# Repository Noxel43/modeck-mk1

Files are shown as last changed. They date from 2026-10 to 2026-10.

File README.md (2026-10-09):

# modeck. mk1

*A fully open-source, DIY MP3 Player*

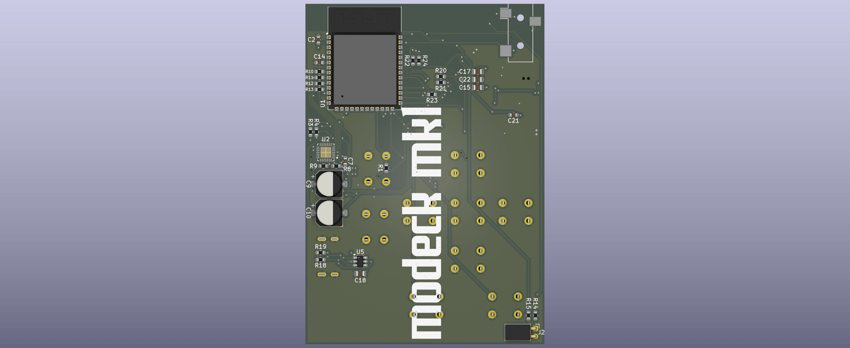
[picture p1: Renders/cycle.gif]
PCB Render


## Core Features:
- Loads of buttons (9) that are each mappable
- ~~Lovely tactile feel~~ (I lie, currently, for prototyping, I'm just using 6mm tacts, however, I really want to incorporate keyboard switches)
- Physical EQ. A potentiometer (currently twist, but I will make it slide) that controls the EQ
- Colour LCD screen (170x320 res)
- USB-C charging (I plan to incorporate pogo pins on the back)
- SD card for storage - easily transfer songs
- Stereo audio (why am I mentioning this, who wants a mono mp3 player?)
- 2 Layer PCB. The PCB consists of only two layers, so its cheap to produce.
- Possible WiFi/BT. For the PCB, I am using the [ESP32-S3-WROOM-1](https://www.altronics.com.au/product/z6433-esp-32s3-development-board), which has WiFi and a built in atenna. It's not currently a priority, but streaming, or at least downloading from wifi would be cool.

## Core Components:
***Note:** This is the list of* main *components, not a full BOM, which will be added later.*
- [ESP32-S3-WROOM-1](https://www.altronics.com.au/product/z6433-esp-32s3-development-board)
  - This is the main MCU, i.e. the brains
- [ES8388](http://lcsc.com/product-detail/C365736.html)
  - This is the audio codec, handling all of the audio output
- [Waveshare 1.9" LCD screen, SKU: 23822](https://www.waveshare.com/1.9inch-lcd-module.htm)
  - Used as the screen (duh). Can be substituted for any 1.9" screen.
- [Battery](https://www.youtube.com/watch?v=dQw4w9WgXcQ&list=RDdQw4w9WgXcQ&start_radio=1)
  - I'm writing this on my school laptop and I can't remember what I'm using specifically, but it's a LiPo. Watch this spot.

## Specifications:

placeholder

## Timeline:

#### **Current Phase:** Prototyping & EVT

*making sure everything works, not yet usable by public*
***Timeframe:** next month or two*

**Current:** PCB design done

**Next:**
- [ ] Make basic firmware for audio playback only
- [ ] Add input handling for all buttons
- [ ] Add a GUI for the screens
- [ ] Add EQ

#### **Next Phase:** DVT & Release

*design validation test, i.e. adding the case, etc*
***Timeframe (from phase start):** ~1 month*

- [ ] Create enclosure
- [ ] Ensure easy printability and assembly
- [ ] Publish v1 with guides, etc, ready without a polished firmware, if people want to make their own.
- [ ] Polish firmware, add different modes, and a good UI/UX
- [ ] Release full.

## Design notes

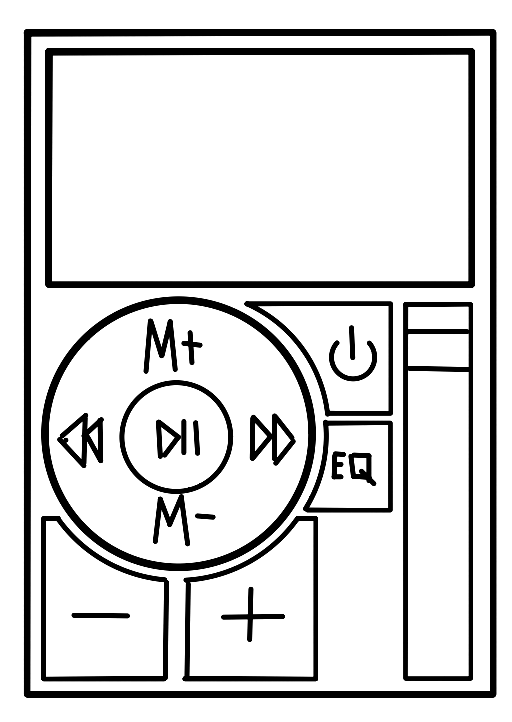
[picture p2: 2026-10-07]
ref.png

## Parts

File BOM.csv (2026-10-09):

Ref | Qty | Value | Unit | Price (ea) | Price (tot) | Footprint/Type | MFN | Link
C1 | 1 | 22 | µF | $- | $- | Capacitor_SMD:C_0805_2012Metric | CL21A226MAQNNNE | https://www.digikey.com/en/products/result?keywords=CL21A226MAQNNNE
C2,C4,C5,C14,C16,C21 | 6 | 100 | nF | $- | $- | Capacitor_SMD:C_0603_1608Metric | GRM188R71H104KA93D | https://www.digikey.com/en/products/result?keywords=GRM188R71H104KA93D
C3,C6,C7,C11,C12,C13 | 6 | 1 | µF | $- | $- | Capacitor_SMD:C_0603_1608Metric | CL10A105KB8NNNC | https://www.digikey.com/en/products/result?keywords=CL10A105KB8NNNC
C8,C15,C17,C18,C22 | 5 | 10 | µF | $- | $- | Capacitor_SMD:C_0805_2012Metric | CL21A106KAYNNNE | https://www.digikey.com/en/products/result?keywords=CL21A106KAYNNNE
C9,C10 | 2 | 220 | µF | $- | $- | Capacitor_SMD:CP_Elec_6.3x5.4 | EEE-FK0J221P | https://www.digikey.com/en/products/result?keywords=EEE-FK0J221P
C19,C20 | 2 | 4.7 | µF | $- | $- | Capacitor_SMD:C_0805_2012Metric | CL21A475KAQNNNE | https://www.digikey.com/en/products/result?keywords=CL21A475KAQNNNE
D1 | 1 | LED | N/A | $0.19 | $0.19 | LED_SMD:LED_0603_1608Metric | 150060VS55040 | https://www.digikey.com/en/products/detail/w%C3%BCrth-elektronik/150060VS55040/8557182
J1 | 1 | AudioJack3 | N/A | $0.68 | $0.68 | Connector_Audio:Jack_3.5mm_CUI_SJ-3523-SMT_Horizontal | STX-3000 | https://www.digikey.com/en/products/result?keywords=STX-3000
J2 | 1 | Battery | N/A | $- | $- | Connector_PinSocket_2.00mm:PinSocket_1x02_P2.00mm_Horizontal | N/A
J3 | 1 | USB_C | N/A | $2.35 | $2.35 | Connector_USB:USB_C_Receptacle_Amphenol_124019772112A | 124019772112A | https://www.digikey.com/en/products/detail/amphenol-cs-commercial-products/124019772112A/13683231
J4 | 1 | Micro_SD_Card | N/A | $3.41 | $3.41 | Connector_Card:microSD_HC_Wuerth_693072010801 | 6.93072E+11 | https://www.digikey.com/en/products/detail/w%C3%BCrth-elektronik/693072010801/3124584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
J5 | 1 | TFT SPI | N/A | $- | $- | Connector_JST:JST_GH_SM08B-GHS-TB_1x08-1MP_P1.25mm_Horizontal | N/A
R1,R2,R5,R6,R8,R9,R20,R21,R22,R23,R24 | 11 | 10 | kΩ | $- | $- | Resistor_SMD:R_0603_1608Metric | RC0603FR-0710KL | https://www.digikey.com/en/products/result?keywords=RC0603FR-0710KL
R3 | 1 | 5.1 | Ω | $- | $- | Resistor_SMD:R_0603_1608Metric | RC0603FR-075R1L | https://www.digikey.com/en/products/result?keywords=RC0603FR-075R1L
R4 | 1 | 4.7 | Ω | $- | $- | Resistor_SMD:R_0603_1608Metric | RC0603FR-074R7L | https://www.digikey.com/en/products/result?keywords=RC0603FR-074R7L
R7 | 1 | 0 | Ω | $- | $- | Resistor_SMD:R_0603_1608Metric | RC0603JR-070RL | https://www.digikey.com/en/products/result?keywords=RC0603JR-070RL
R10,R11,R12,R13 | 4 | 33 | Ω | $- | $- | Resistor_SMD:R_0603_1608Metric | RC0603FR-0733RL | https://www.digikey.com/en/products/result?keywords=RC0603FR-0733RL
R14,R15 | 2 | 100 | kΩ | $- | $- | Resistor_SMD:R_0603_1608Metric | RC0603FR-07100KL | https://www.digikey.com/en/products/result?keywords=RC0603FR-07100KL
R16 | 1 | 1 | kΩ | $- | $- | Resistor_SMD:R_0603_1608Metric | RC0603FR-071KL | https://www.digikey.com/en/products/result?keywords=RC0603FR-071KL
R17 | 1 | 2 | kΩ | $- | $- | Resistor_SMD:R_0603_1608Metric | RC0603FR-072KL | https://www.digikey.com/en/products/result?keywords=RC0603FR-072KL
R18,R19 | 2 | 5.1 | kΩ | $- | $- | Resistor_SMD:R_0603_1608Metric | RC0603FR-075K1L | https://www.digikey.com/en/products/result?keywords=RC0603FR-075K1L
RV1 | 1 | Slide pot | N/A | $0.28 | $0.28 | Potentiometer_SMD:Potentiometer_ACP_CA6-VSMD_Vertical | TC33X-2-203E | https://www.digikey.com/en/products/detail/bourns-inc/TC33X-2-203E/2566887
SW1 | 1 | Play | N/A | $0.10 | $0.10 | Button_Switch_THT:SW_PUSH_6mm_H4.3mm | 1825910-6 | https://www.digikey.com/en/products/result?keywords=1825910-6
SW2 | 1 | Trk Prev | N/A | $0.10 | $0.10 | Button_Switch_THT:SW_PUSH_6mm_H4.3mm | 1825910-6 | https://www.digikey.com/en/products/result?keywords=1825910-6
SW3 | 1 | Trk Next | N/A | $0.10 | $0.10 | Button_Switch_THT:SW_PUSH_6mm_H4.3mm | 1825910-6 | https://www.digikey.com/en/products/result?keywords=1825910-6
SW4 | 1 | Mode Prev | N/A | $0.10 | $0.10 | Button_Switch_THT:SW_PUSH_6mm_H4.3mm | 1825910-6 | https://www.digikey.com/en/products/result?keywords=1825910-6
SW5 | 1 | Mode Next | N/A | $0.10 | $0.10 | Button_Switch_THT:SW_PUSH_6mm_H4.3mm | 1825910-6 | https://www.digikey.com/en/products/result?keywords=1825910-6
SW6 | 1 | Eq | N/A | $0.10 | $0.10 | Button_Switch_THT:SW_PUSH_6mm_H4.3mm | 1825910-6 | https://www.digikey.com/en/products/result?keywords=1825910-6
SW7 | 1 | Power | N/A | $0.10 | $0.10 | Button_Switch_THT:SW_PUSH_6mm_H4.3mm | 1825910-6 | https://www.digikey.com/en/products/result?keywords=1825910-6
SW8 | 1 | RESET | N/A | $0.58 | $0.58 | Button_Switch_SMD:SW_SPST_PTS810 | PTS810SJM250SMTR LFS | https://www.digikey.com/en/products/detail/c-k/PTS810SJM250SMTR-LFS/4176610
SW9 | 1 | BOOT | N/A | $0.58 | $0.58 | Button_Switch_SMD:SW_SPST_PTS810 | PTS810SJM250SMTR LFS | https://www.digikey.com/en/products/detail/c-k/PTS810SJM250SMTR-LFS/4176610
SW10 | 1 | Power_sw | N/A | $2.51 | $2.51 | Button_Switch_SMD:SW_DIP_SPSTx01_Slide_6.7x4.1mm_W6.73mm_P2.54mm_LowProfile_JPin | SDA01H1SBD | https://www.digikey.com/en/products/detail/c-k/SDA01H1SBD/2263273
SW11 | 1 | Next | N/A | $0.10 | $0.10 | Button_Switch_THT:SW_PUSH_6mm_H4.3mm | 1825910-6 | https://www.digikey.com/en/products/result?keywords=1825910-6
SW12 | 1 | Prev | N/A | $0.10 | $0.10 | Button_Switch_THT:SW_PUSH_6mm_H4.3mm | 1825910-6 | https://www.digikey.com/en/products/result?keywords=1825910-6
U1 | 1 | ESP32-S3-WROOM-1 | N/A | $6.10 | $6.10 | RF_Module:ESP32-S3-WROOM-1 | ESP32-S3-WROOM-1-N16 | https://www.digikey.com/en/products/detail/espressif-systems/esp32-s3-wroom-1-n16/16162647
U2 | 1 | ES8388 | N/A | $1.12 | $1.12 | Package_DFN_QFN:QFN-28-1EP_4x4mm_P0.45mm_EP2.6x2.6mm | ES8388 | https://www.lcsc.com/product-detail/C365736.html
U3 | 1 | AP2112K-3.3 | N/A | $0.28 | $0.28 | Package_TO_SOT_SMD:SOT-23-5 | AP2112K-3.3TRG1 | https://www.digikey.com/en/products/detail/diodes-incorporated/ap2112k-3-3trg1/4470746
U4 | 1 | MCP73831-2-OT | N/A | $0.76 | $0.76 | Package_TO_SOT_SMD:SOT-23-5 | MCP73831T-2ACI/OT | https://www.digikey.com/en/products/detail/microchip-technology/MCP73831T-2ACI-OT/964301
U5 | 1 | USBLC6-2SC6 | N/A | $0.86 | $0.86 | Package_TO_SOT_SMD:SOT-23-6 | USBLC6-2SC6 | https://www.digikey.com/en/products/detail/goodwork/usblc6-2sc6/29515591
Screen | 1 | 1.9 | " | $11.99 | $11.99 | N/A | 23822 | https://www.waveshare.com/1.9inch-lcd-module.htm
Battery | 1 | 2000 | mA | $14.45 | $10.00 | N/A | CE04378 | https://core-electronics.com.au/polymer-lithium-ion-battery-2000mah-38459.html
Capacitors + Resistors | 1 | Just approx | N/A | 10 | $10.00
Total |  |  |  |  | $52.59

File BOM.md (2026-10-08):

# modeck mk1 – bill of materials

<!-- Generated by Half Life from project cmuur4mu709pu01smvrzood28. Edits here are overwritten on the next sync. -->
<!-- Generated: 1970-01-01T00:00:00.000Z -->

> [!NOTE]
> This parts list is mirrored from [Half Life](https://halflife.hackclub.com). Editing it here will not change the platform's copy, and the next sync overwrites this file.

| Week | Tier | Parts funding |
| --- | --- | --- |
| Week 1 | Tier 2 | $65.00 |

_No parts listed yet._

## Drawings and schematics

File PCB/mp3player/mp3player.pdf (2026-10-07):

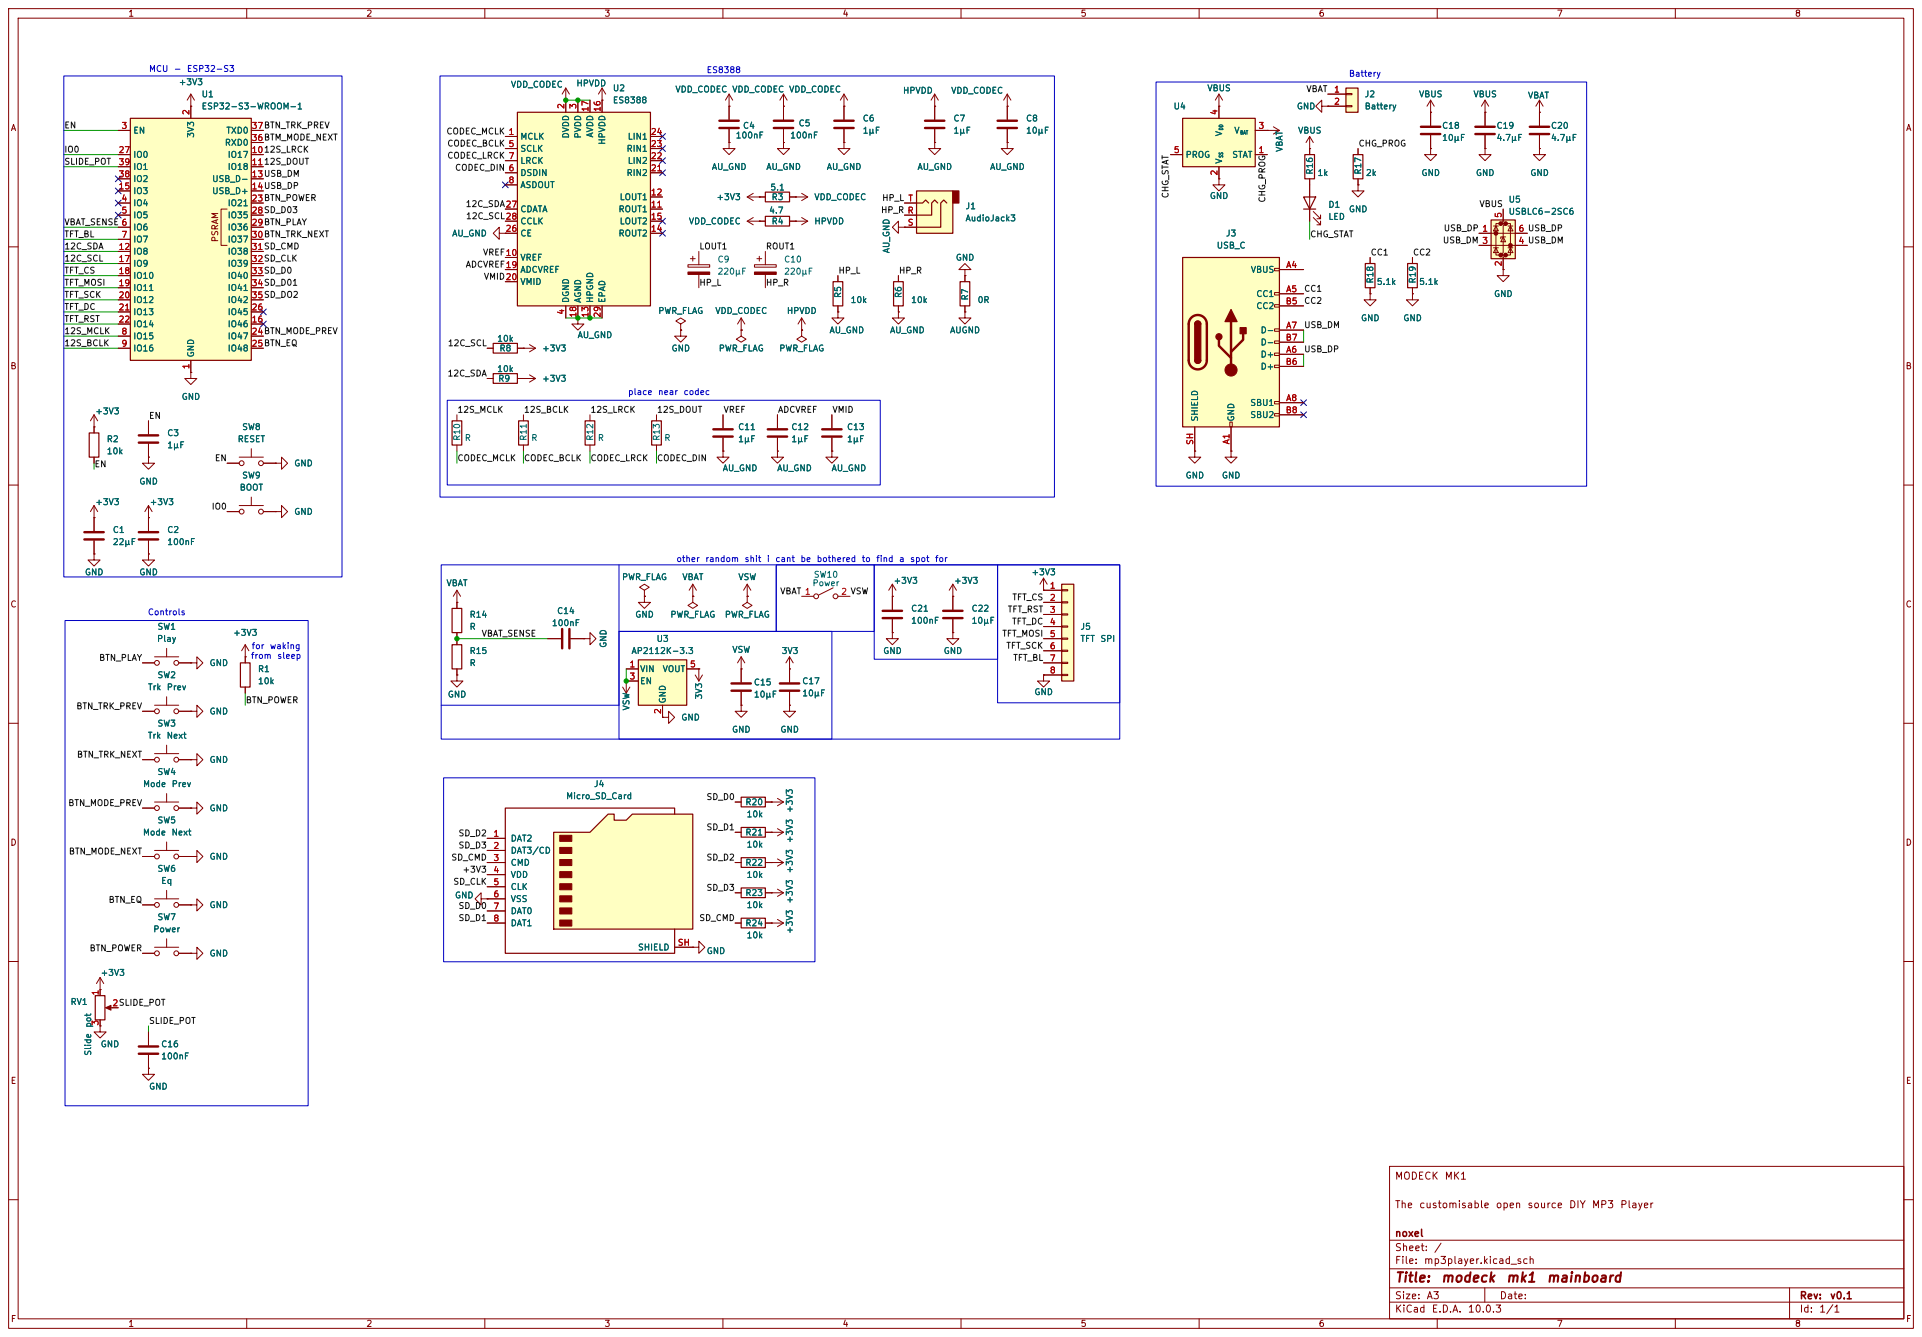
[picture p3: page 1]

other random shit i cant be bothered to find a spot for +3V3U1

Trk Prev SW5 Mode Next GND

The customisable open source DIY MP3 Player

Size: A3 | Rev: v0.1 | F Date:
KiCad E.D.A. 10.0.3 | Id: 1/1

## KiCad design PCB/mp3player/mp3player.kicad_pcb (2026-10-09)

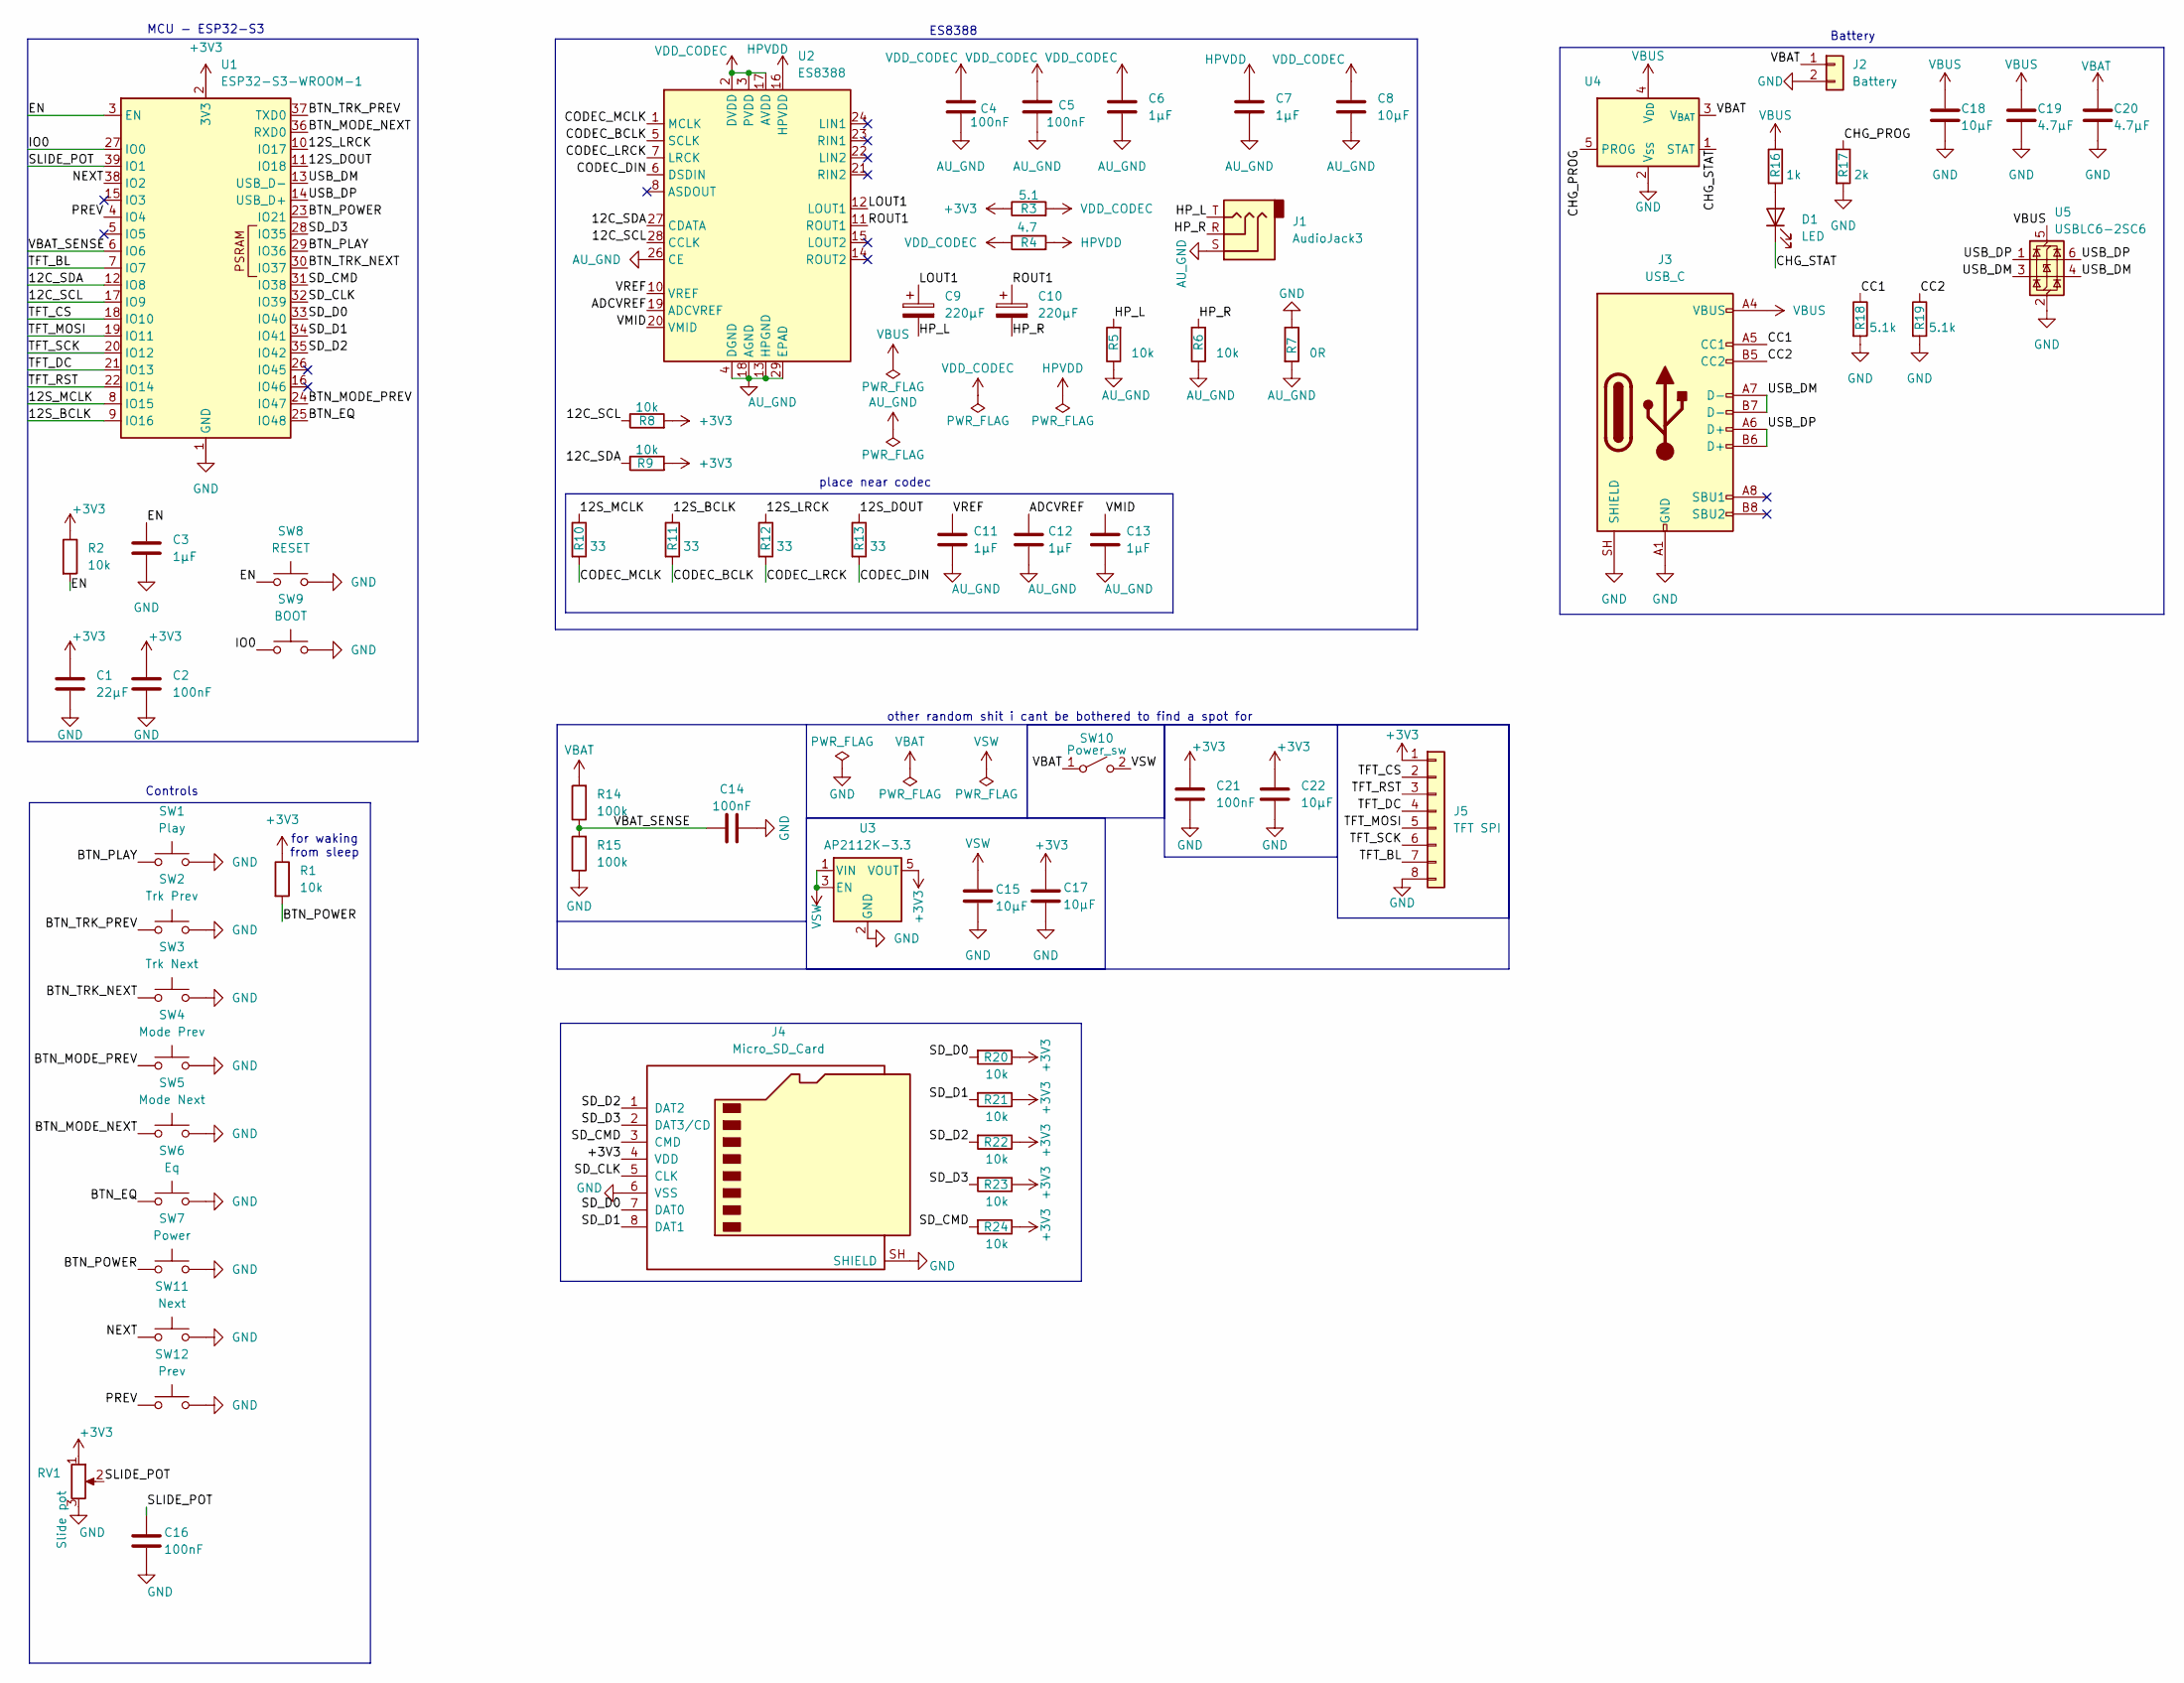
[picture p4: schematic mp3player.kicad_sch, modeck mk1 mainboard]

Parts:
C1: 22μF; C_0805_2012Metric
C2, C4, C5, C14, C16, C21: 100nF; C_0603_1608Metric
C3, C6, C7, C11, C12, C13: 1μF; C_0603_1608Metric
C8, C15, C17, C18, C22: 10μF; C_0805_2012Metric
C9, C10: 220μF; CP_Elec_6.3x5.4
C19, C20: 4.7μF; C_0805_2012Metric
D1: LED; LED_0603_1608Metric
J1: AudioJack3; Jack_3.5mm_CUI_SJ-3523-SMT_Horizontal
J2: Battery; PinSocket_1x02_P2.00mm_Horizontal
J3: USB_C; USB_C_Receptacle_Amphenol_124019772112A
J4: Micro_SD_Card; microSD_HC_Wuerth_693072010801
J5: TFT SPI; JST_GH_SM08B-GHS-TB_1x08-1MP_P1.25mm_Horizontal
R1, R2, R5, R6, R8, R9, R20, R21, R22, R23, R24: 10k; R_0603_1608Metric
R3: 5.1; R_0603_1608Metric
R4: 4.7; R_0603_1608Metric
R7: 0R; R_0603_1608Metric
R10, R11, R12, R13: 33; R_0603_1608Metric
R14, R15: 100k; R_0603_1608Metric
R16: 1k; R_0603_1608Metric
R17: 2k; R_0603_1608Metric
R18, R19: 5.1k; R_0603_1608Metric
RV1: Slide pot; Potentiometer_ACP_CA6-VSMD_Vertical
SW1: Play; SW_PUSH_6mm_H4.3mm
SW2: Trk Prev; SW_PUSH_6mm_H4.3mm
SW3: Trk Next; SW_PUSH_6mm_H4.3mm
SW4: Mode Prev; SW_PUSH_6mm_H4.3mm
SW5: Mode Next; SW_PUSH_6mm_H4.3mm
SW6: Eq; SW_PUSH_6mm_H4.3mm
SW7: Power; SW_PUSH_6mm_H4.3mm
SW8: RESET; SW_SPST_PTS810
SW9: BOOT; SW_SPST_PTS810
SW10: Power_sw; SW_DIP_SPSTx01_Slide_6.7x4.1mm_W6.73mm_P2.54mm_LowProfile_J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
SW11: Next; SW_PUSH_6mm_H4.3mm
SW12: Prev; SW_PUSH_6mm_H4.3mm
U1: ESP32-S3-WROOM-1
U2: ES8388; QFN-28-1EP_4x4mm_P0.45mm_EP2.6x2.6mm
U3: AP2112K-3.3; SOT-23-5
U4: MCP73831-2-OT; SOT-23-5
U5: USBLC6-2SC6; SOT-23-6

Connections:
+3V3: C1.1, C2.1, C17.1, C21.1, C22.1, J4.4 (VDD), J5.1, R1.1, R2.1, R3.1, R8.2, R9.2, R20.1, R21.1, R22.1, R23.1, R24.1, RV1.1, U1.2 (3V3), U3.5 (VOUT)
/12C_SCL: R8.1, U1.17 (IO9), U2.28 (CCLK)
/12C_SDA: R9.1, U1.12 (IO8), U2.27 (CDATA)
/12S_BCLK: R11.1, U1.9 (IO16)
/12S_DOUT: R13.1, U1.11 (IO18)
/12S_LRCK: R12.1, U1.10 (IO17)
/12S_MCLK: R10.1, U1.8 (IO15)
/ADCVREF: C12.1, U2.19 (ADCVREF)
/BTN_EQ: SW6.1, U1.25 (IO48)
/BTN_MODE_NEXT: SW5.1, U1.36 (RXD0)
/BTN_MODE_PREV: SW4.1, U1.24 (IO47)
/BTN_PLAY: SW1.1, U1.29 (IO36)
/BTN_POWER: R1.2, SW7.1, U1.23 (IO21)
/BTN_TRK_NEXT: SW3.1, U1.30 (IO37)
/BTN_TRK_PREV: SW2.1, U1.37 (TXD0)
/CC1: J3.A5 (CC1), R18.1
/CC2: J3.B5 (CC2), R19.1
/CHG_PROG: R17.1, U4.5 (PROG)
/CHG_STAT: D1.1 (K), U4.1 (STAT)
/CODEC_BCLK: R11.2, U2.5 (SCLK)
/CODEC_DIN: R13.2, U2.6 (DSDIN)
/CODEC_LRCK: R12.2, U2.7 (LRCK)
/CODEC_MCLK: R10.2, U2.1 (MCLK)
/EN: C3.1, R2.2, SW8.1, U1.3 (EN)
/HP_L: C9.2, J1.T, R5.2
/HP_R: C10.2, J1.R, R6.2
/IO0: SW9.1, U1.27 (IO0)
/LOUT1: C9.1, U2.12 (LOUT1)
/NEXT: SW11.1, U1.38 (IO2)
/PREV: SW12.1, U1.4 (IO4)
/ROUT1: C10.1, U2.11 (ROUT1)
/SD_CLK: J4.5 (CLK), U1.32 (IO39)
/SD_CMD: J4.3 (CMD), R24.2, U1.31 (IO38)
/SD_D0: J4.7 (DAT0), R20.2, U1.33 (IO40)
/SD_D1: J4.8 (DAT1), R21.2, U1.34 (IO41)
/SD_D2: J4.1 (DAT2), R22.2, U1.35 (IO42)
/SD_D3: J4.2 (DAT3/CD), R23.2, U1.28 (IO35)
/SLIDE_POT: C16.1, RV1.2, U1.39 (IO1)
/TFT_BL: J5.7, U1.7 (IO7)
/TFT_CS: J5.2, U1.18 (IO10)
/TFT_DC: J5.4, U1.21 (IO13)
/TFT_MOSI: J5.5, U1.19 (IO11)
/TFT_RST: J5.3, U1.22 (IO14)
/TFT_SCK: J5.6, U1.20 (IO12)
/USB_DM: J3.A7 (D-), J3.B7 (D-), U1.13 (USB_D-), U5.3 (I/O2), U5.4 (I/O2)
/USB_DP: J3.A6 (D+), J3.B6 (D+), U1.14 (USB_D+), U5.1 (I/O1), U5.6 (I/O1)
/VBAT_SENSE: C14.1, R14.1, R15.2, U1.6 (IO6)
/VMID: C13.1, U2.20 (VMID)
/VREF: C11.1, U2.10 (VREF)
AU_GND: C4.2, C5.2, C6.2, C7.2, C8.2, C11.2, C12.2, C13.2, J1.S, R5.1, R6.1, R7.2, U2.4 (DGND), U2.13 (HPGND), U2.18 (AGND), U2.26 (CE), U2.29 (EPAD)
GND: C1.2, C2.2, C3.2, C14.2, C15.2, C16.2, C17.2, C18.2, C19.2, C20.2, C21.2, C22.2, J2.2, J3.A1 (GND), J3.A12 (GND), J3.B1 (GND), J3.B12 (GND), J3.SH (SHIELD), J4.6 (VSS), J4.SH (SHIELD), J5.8, R7.1, R15.1, R17.2, R18.2, R19.2, RV1.3, SW1.2, SW2.2, SW3.2, SW4.2, SW5.2, SW6.2, SW7.2, SW8.2, SW9.2, SW11.2, SW12.2, U1.1 (GND), U1.40 (GND), U1.41 (GND), U3.2 (GND), U4.2 (V_{SS}), U5.2 (GND)
HPVDD: C7.1, R4.2, U2.16 (HPVDD)
unnamed: D1.2 (A), R16.2
VBAT: C20.1, J2.1, R14.2, SW10.1 (A), U4.3 (V_{BAT})
VBUS: C18.1, C19.1, J3.A4 (VBUS), J3.A9 (VBUS), J3.B4 (VBUS), J3.B9 (VBUS), R16.1, U4.4 (V_{DD}), U5.5 (VBUS)
VDD_CODEC: C4.1, C5.1, C6.1, C8.1, R3.2, R4.1, U2.2 (DVDD), U2.3 (PVDD), U2.17 (AVDD)
VSW: C15.1, SW10.2 (B), U3.1 (VIN), U3.3 (EN)

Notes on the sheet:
Battery
MCU - ESP32-S3
for waking from sleep
ES8388
place near codec
other random shit i cant be bothered to find a spot for
Controls

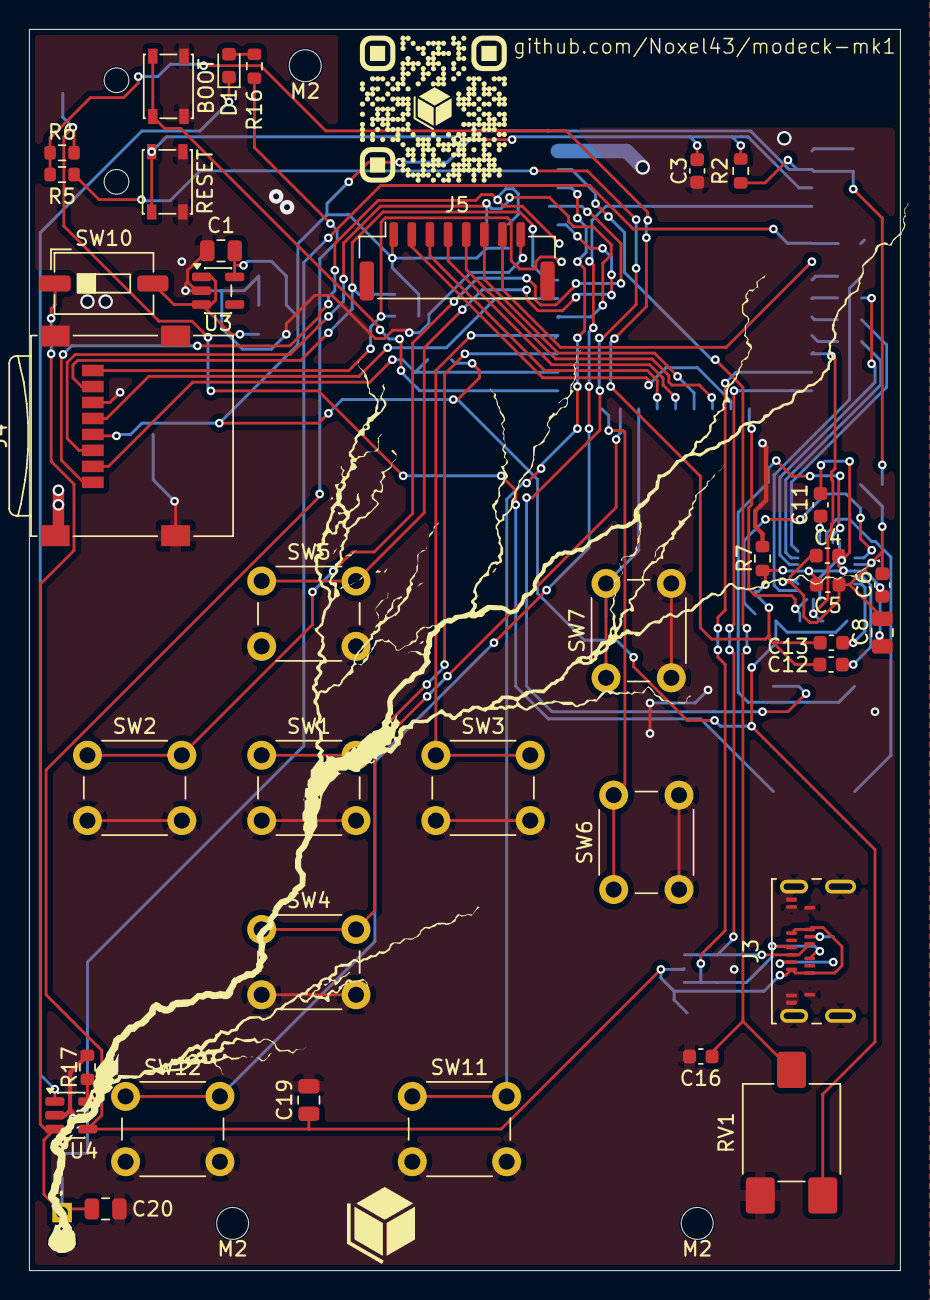
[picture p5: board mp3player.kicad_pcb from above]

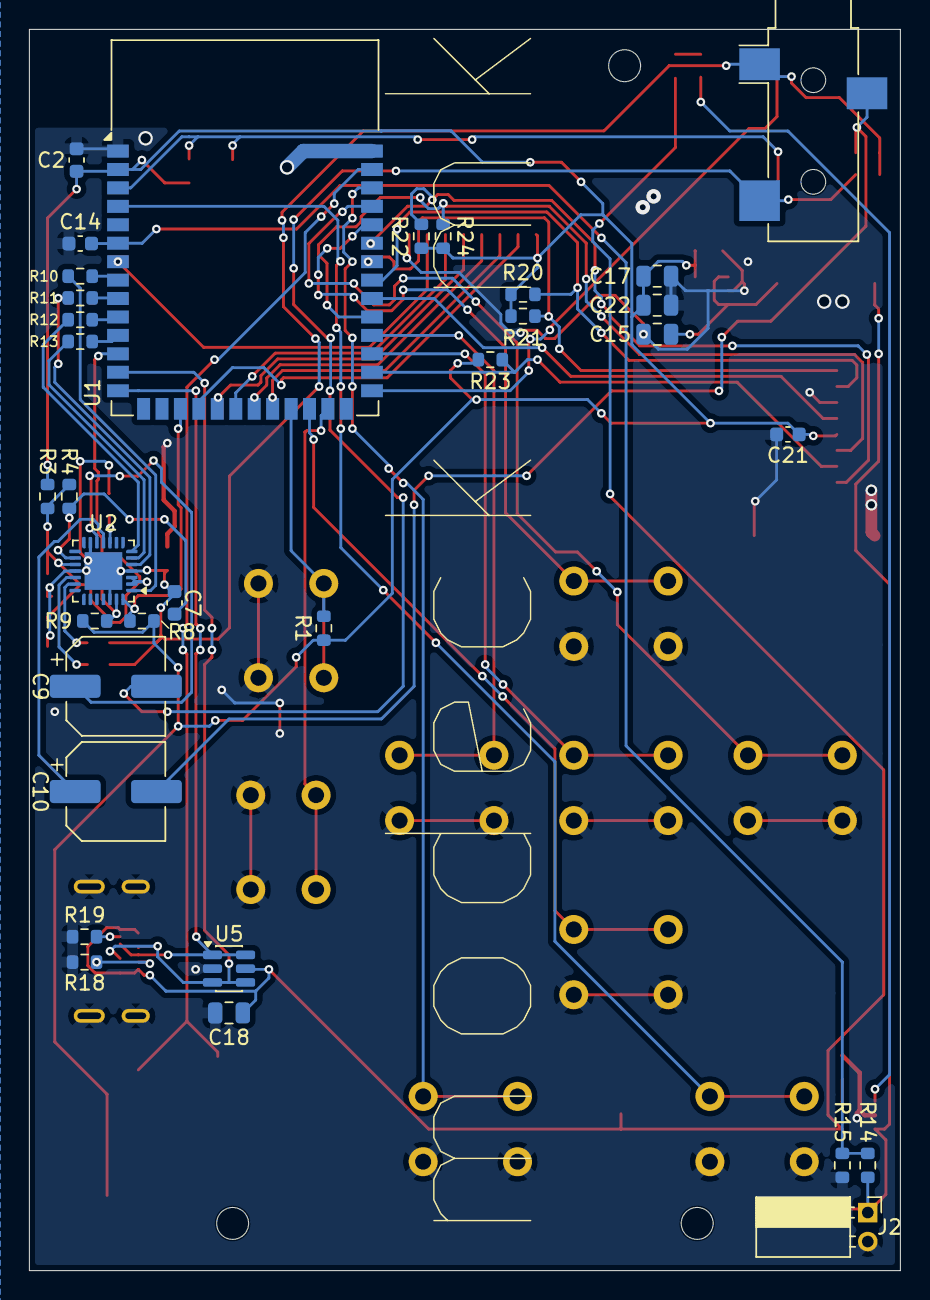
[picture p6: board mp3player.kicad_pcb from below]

Board: 2 copper layers, 60.0 x 85.5 mm, 73 parts (33 on the bottom side), 57 nets.

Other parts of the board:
M2, M2#2, M2#3: MountingHole_2.2mm_M2

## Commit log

2026-10-06 SCH Save
    [mp3player.kicad_sch]
2026-10-07 ERC is clean
    [mp3player.kicad_sch]
2026-10-07 turned off kicad git
2026-10-07 fixed proj location
    [mp3player.kicad_pcb, mp3player.kicad_sch]
2026-10-07 added footprints for smds
    [mp3player.kicad_pcb, mp3player.kicad_sch]
2026-10-07 added footprints
    [mp3player.kicad_sch]
2026-10-07 updated footprints, starting on pcb
    [mp3player.kicad_pcb, mp3player.kicad_sch]
2026-10-07 started on placement
    [mp3player.kicad_pcb]
2026-10-07 worked on pcb
    [mp3player.kicad_pcb, mp3player.kicad_sch]
2026-10-07 keys are connected
    [mp3player.kicad_pcb]
2026-10-07 sd pullups done
    [mp3player.kicad_pcb]
2026-10-07 all parts placed
    [mp3player.kicad_pcb]
2026-10-08 audio gnd fully routed
    [mp3player.kicad_pcb]
2026-10-08 3V3 net routing done :)
    [mp3player.kicad_pcb]
2026-10-08 fuck my life
    [mp3player.kicad_pcb]
2026-10-08 its a bit better now
    [mp3player.kicad_pcb]
2026-10-09 added BOM
    [BOM.csv, BOM.xlsx, mp3player.kicad_sch]
2026-10-09 working on drc
    [mp3player.kicad_pcb]
2026-10-09 No DRC errors, fuck warnings
    [mp3player.kicad_pcb]
2026-10-09 drc is CLEAN isudhfguoishgf
    [mp3player.kicad_pcb]
2026-10-09 started on silkscreen design
    [mp3player.kicad_pcb]
2026-10-09 board design
    [mp3player.kicad_pcb]
2026-10-09 added gif to readme
    Added a PCB render image and updated feature descriptions.
2026-10-09 added m2 mounting holes
    [mp3player.kicad_pcb]
2026-10-09 gerbers done
    [mp3player.kicad_pcb]
2026-10-09 updated BOM.csv
    [BOM.csv, BOM.xlsx]
2026-10-09 added bom link
    Updated note about main components to include BOM link.
2026-10-12 Change PCB animation from MP4 to GIF
    Updated animation file format from MP4 to GIF.
